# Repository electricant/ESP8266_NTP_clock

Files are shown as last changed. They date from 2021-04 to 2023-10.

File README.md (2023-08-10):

# ESP8266_NTP_clock
Very basic bedside digital clock using the NTP8266 to sync the time using NTP.

## Features

This started as a whish list and expanded during development. Since this is an
open-ended project this list may grow. Never settle!

 * Synchronize time using my local network NTP server
 * Receive and display temperature and humidity readings from my external
   weather station. This way I know at a glance how to get dressed in the
   morning.
 * Backlight support either triggered by a button or automating using a
   photoresistor
 * DST support without requiring an external library

## Firmware

Required libraries:
 * PubSubClient
 * TimeLib
 * ArduinoJson
 * [qd_sched](https://github.com/electricant/qd_sched) - simple scheduler for repetitive tasks

The code uses a local, improved version of the EasyNTPClient library. It is
available as a git submodule.

## PCB/Mechanical assembly

There's not much to it actually. Just a PCB the same size of the display.
The display board and the control PCB are sandwiched together using M2.5 hex
standoffs. The display conencts to the mainboard using 2.54mm headers.

## Pictures

3D rendering of the PCB:
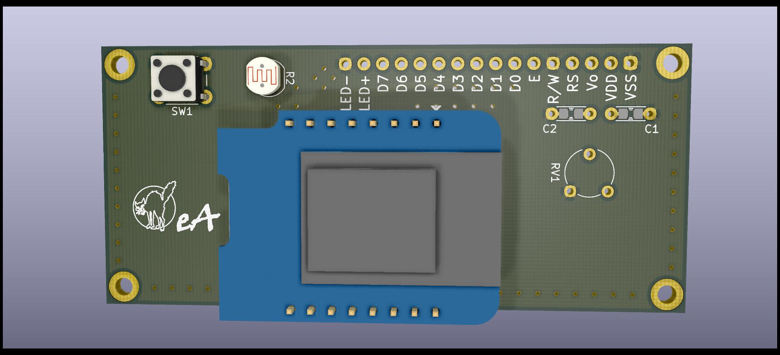
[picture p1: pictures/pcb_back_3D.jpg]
PCB 3D rendering


Prototype (I swear it is not a bomb officer):
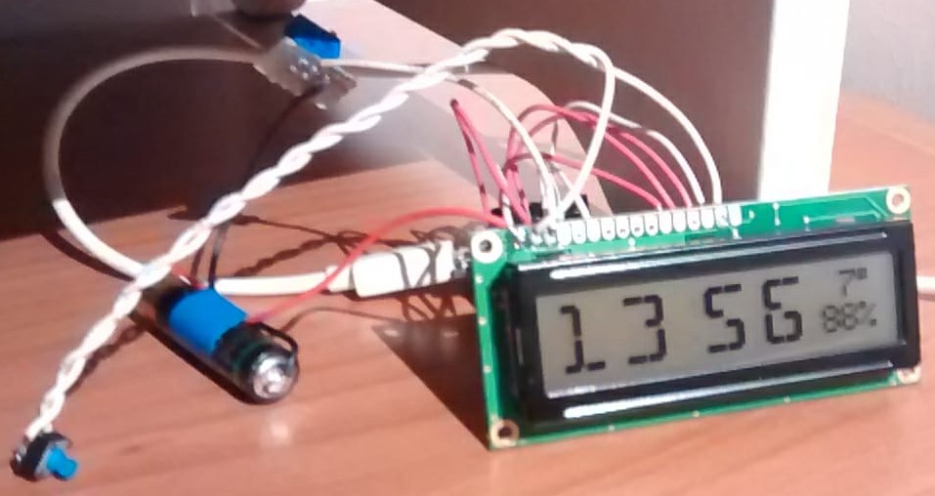
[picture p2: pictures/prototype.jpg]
prototype


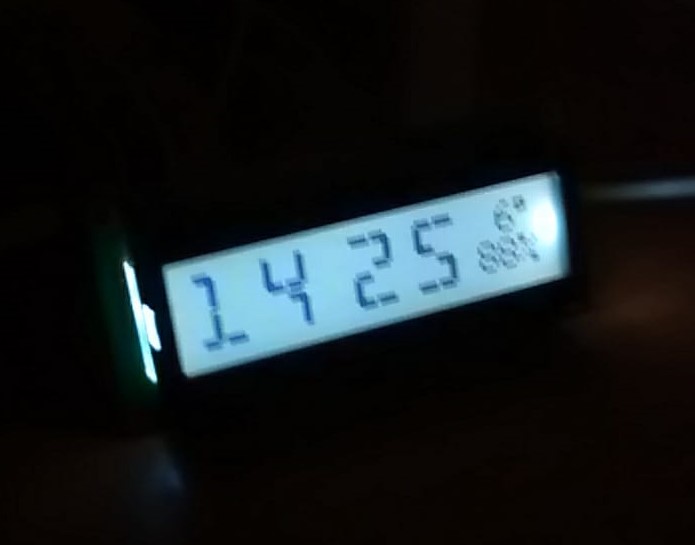
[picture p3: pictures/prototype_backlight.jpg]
prototype backlight


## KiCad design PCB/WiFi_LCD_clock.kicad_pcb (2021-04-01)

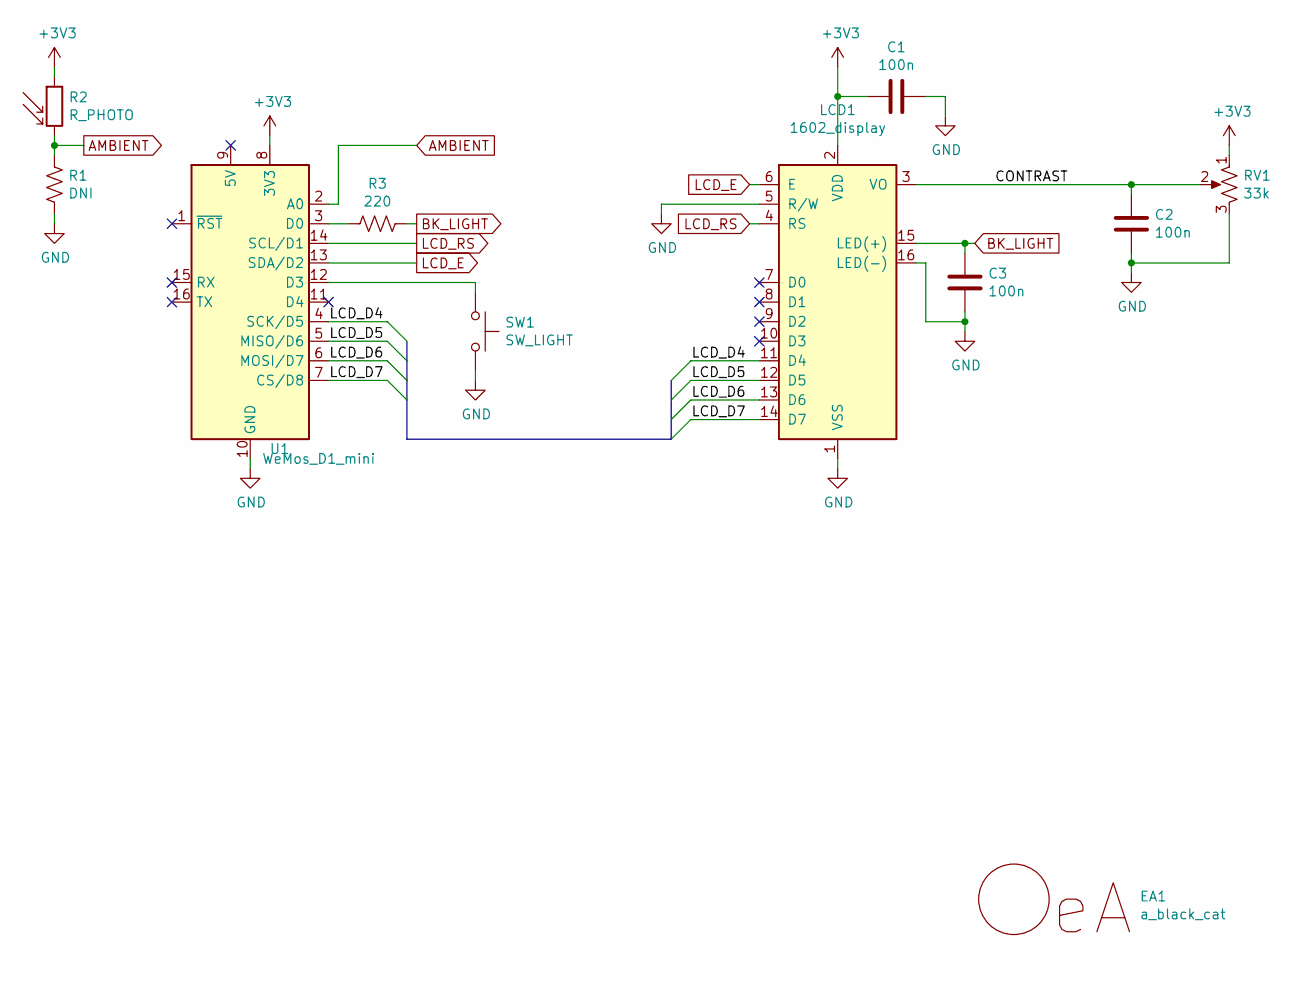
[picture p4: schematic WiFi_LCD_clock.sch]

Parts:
C1, C2, C3: 100n; universal_cap
EA1: a_black_cat
LCD1: 1602_display; 1602_lcd
R1: DNI; universal_res
R2: R_PHOTO; R_LDR_4.9x4.2mm_P2.54mm_Vertical
R3: 220; universal_res
RV1: 33k; Potentiometer_Piher_PT-6-V_Vertical
SW1: SW_LIGHT; SW_PUSH_6mm
U1: WeMos_D1_mini; WEMOS_D1_mini_light

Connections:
+3V3: C1.2, LCD1.2 (VDD), R2.1, RV1.1, U1.8 (3V3)
/CONTRAST: C2.1, LCD1.3 (VO), RV1.2
/LCD_D4: LCD1.11 (D4), U1.4 (SCK/D5)
/LCD_D5: LCD1.12 (D5), U1.5 (MISO/D6)
/LCD_D6: LCD1.13 (D6), U1.6 (MOSI/D7)
/LCD_D7: LCD1.14 (D7), U1.7 (CS/D8)
AMBIENT: R1.1, R2.2, U1.2 (A0)
BK_LIGHT: C3.1, LCD1.15 (LED(+)), R3.1
GND: C1.1, C2.2, C3.2, LCD1.1 (VSS), LCD1.5 (R/W), LCD1.16 (LED(-)), R1.2, RV1.3, SW1.2, U1.10 (GND)
LCD_E: LCD1.6 (E), U1.13 (SDA/D2)
LCD_RS: LCD1.4 (RS), U1.14 (SCL/D1)
unnamed: R3.2, U1.3 (D0)
unnamed: SW1.1, U1.12 (D3)

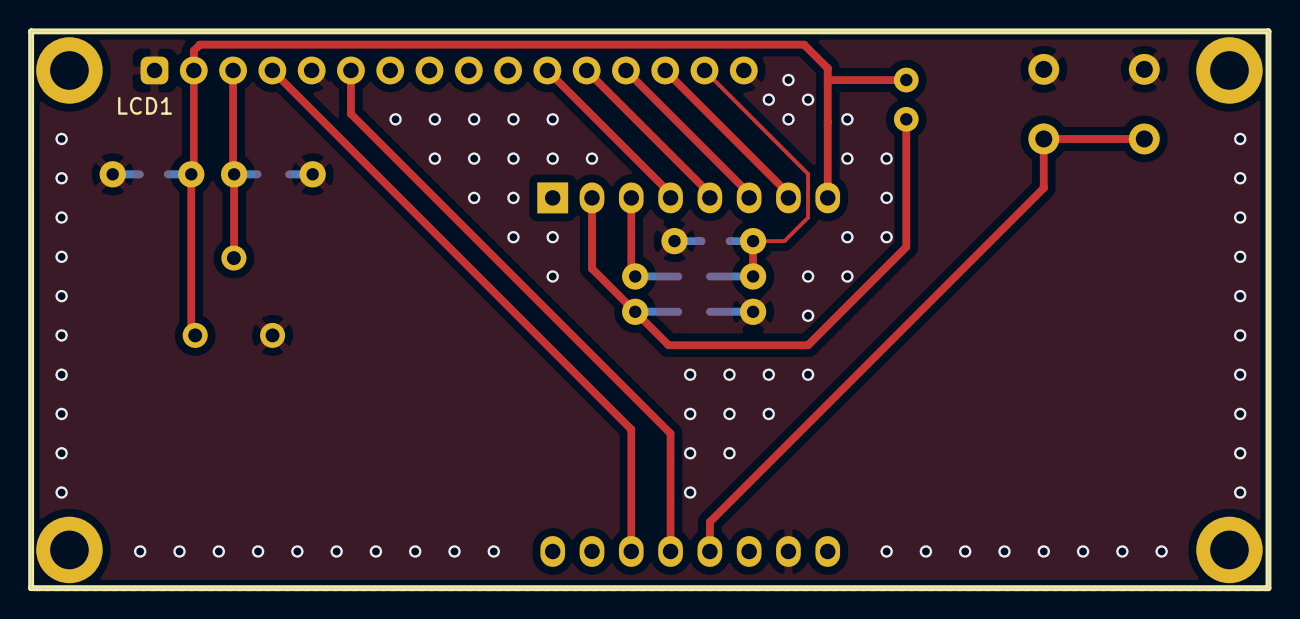
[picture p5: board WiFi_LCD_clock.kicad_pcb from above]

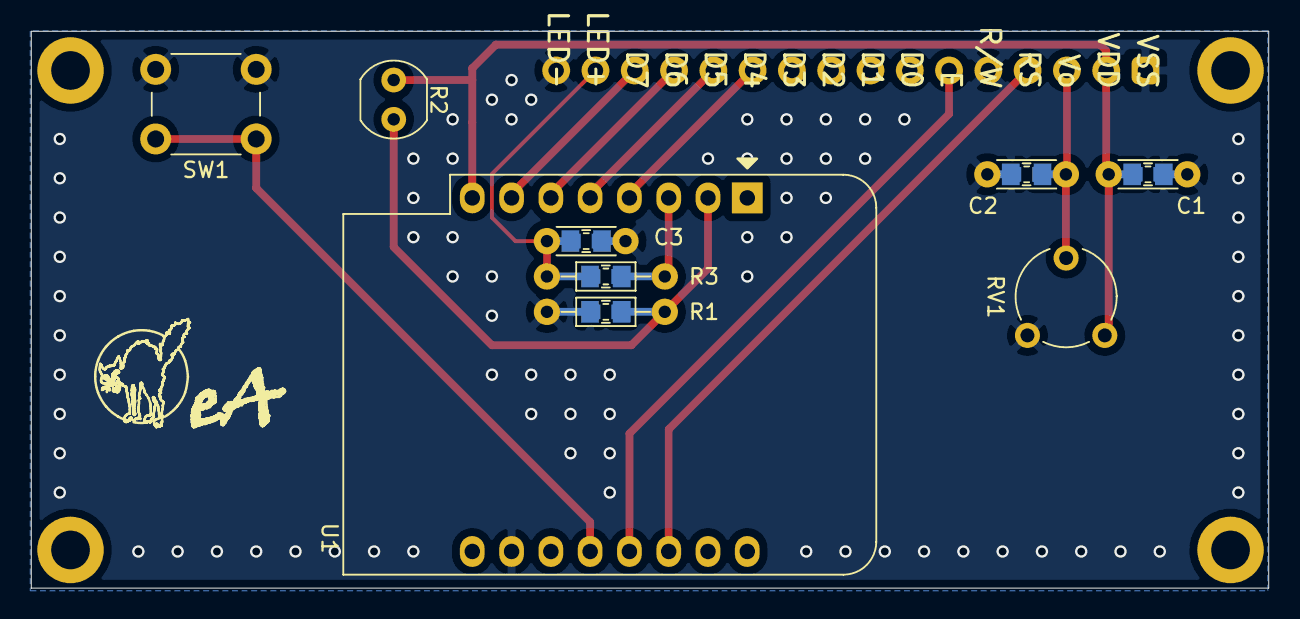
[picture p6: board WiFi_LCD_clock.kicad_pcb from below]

Board: 2 copper layers, 80.0 x 36.0 mm, 11 parts (10 on the bottom side), 13 nets.

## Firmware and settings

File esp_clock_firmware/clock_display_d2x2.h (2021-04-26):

/*
 * Header file for the functions controlling the LCD display of the clock.
 *
 * It uses a 2x2 font for displaying the digits.
 *
 * The fonts are defined by a set of 8 custom chars which, combined, look like
 * digits. The custom chars are loaded when the display is initialized and are
 * defined by the chrN (0<= N < 8) arrays.
 * The way in which the custom chars are combined to form digits is defined in
 * the 'number_chars' array. This array has an entry for each digit. Within this
 * entry the index of the custom chars from left to right, top to bottom is present.	
 */
#ifndef CLOCK_DISPLAY_D2X2_H
#define CLOCK_DISPLAY_D2X2_H

#include <LiquidCrystal.h>
#include <pins_arduino.h>

/*
 * LCD pins definition. As seen in the schematic!
 */
#define LCD_RS D1
#define LCD_E  D2
#define LCD_D4 D5
#define LCD_D5 D6
#define LCD_D6 D7
#define LCD_D7 D8

// Global LCD instance
LiquidCrystal lcd = LiquidCrystal(LCD_RS, LCD_E, LCD_D4, LCD_D5, LCD_D6, LCD_D7);

/*
 * Custom chars
 */
byte chr0[] = {
  B01111,
  B11111,
  B11000,
  B11000,
  B11000,
  B11000,
  B11000,
  B11000
};
byte chr1[] = {
  B11110,
  B11111,
  B00011,
  B00011,
  B00011,
  B00011,
  B00011,
  B00011
};
byte chr2[] = {
  B11000,
  B11000,
  B11000,
  B11000,
  B11000,
  B11000,
  B11111,
  B01111
};
byte chr3[] = {
  B00011,
  B00011,
  B00011,
  B00011,
  B00011,
  B00011,
  B11111,
  B11110
};
byte chr4[] = {
  B11111,
  B11111,
  B00000,
  B00000,
  B00000,
  B00000,
  B00000,
  B00000
};
byte chr5[] = {
  B01111,
  B11111,
  B11000,
  B11000,
  B11000,
  B11000,
  B11111,
  B01111
};
byte chr6[] = {
  B11110,
  B11111,
  B00011,
  B00011,
  B00011,
  B00011,
  B11111,
  B11110
};
byte chr7[] = {
  B00000,
  B00000,
  B00000,
  B00000,
  B00000,
  B00000,
  B11111,
  B11111
};

byte number_chars[10][4] = {
  {0,  1,  2, 3}, // 0
  {1, 32,  3, 7}, // 1
  {4,  6,  5, 7}, // 2
  {4,  6,  7, 3}, // 3
  {2,  3, 32, 1}, // 4
  {5,  4,  7, 6}, // 5
  {5,  4,  2, 6}, // 6
  {4,  1, 32, 0}, // 7
  {5,  6,  2, 3}, // 8
  {5,  6,  7, 3}  // 9 
};

/*
 * Initialize the LCD display
 */
void lcd_init();

/*
 * Prints the given time on the LCD
 */
void lcd_print_time(uint8_t hrs, uint8_t mins);
void lcd_print_time(uint8_t hrs, uint8_t mins, uint8_t sec);

/*
 * Prints temperature and humidity
 */
void lcd_print_temp_humidity(float temp, float hum);

#endif

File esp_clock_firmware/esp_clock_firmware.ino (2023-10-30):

/*
    Digital clock with LCD display using a Wemos D1 / ESP8266

    Features:
     - Time is fetched using NTP
     - Also the weather is fetched from the network
*/
#include <ESP8266WiFi.h>
#include <PubSubClient.h>
#include <WiFiUdp.h>
#include "EasyNTPClient/src/EasyNTPClient.h"
#include "EasyNTPClient/src/EasyNTPClient.cpp"
#include <TimeLib.h>
#include <qd_sched.h>
#include <ArduinoJson.h>

#include "clock_display_d2x2.h"
#include "ash.h"
#include "alogger.h"
#include "config/config.h"

/*
 * Macros for hardware configuration.
 * 
 * See 'clock_display_d2x2.h' for macros defining where the display is connected
 */
// Input pin to enable backlight when pressed
#define BACKLIGHT_BUTTON D3
// Output pin to be used as LCD backlight control
#define BACKLIGHT_PIN D0

/* 
 * The controls for the builtin LED are reversed.
 * When the pin is set to HIGH the LED is off and vice-versa.
 * Those two macors make it easy to set the LED state appropriately.
 */
#define LED_BUILTIN_ON  0
#define LED_BUILTIN_OFF 1

// A UDP instance to let us send and receive packets over UDP
WiFiUDP udp;

// EasyNTPClient instance to fetch the current NTP time
#define OFFSET_FROM_UTC_S ((OFFSET_FROM_UTC_H*60*60)+(OFFSET_FROM_UTC_M*60))
EasyNTPClient ntpClient(udp, NTP_SERVER, OFFSET_FROM_UTC_S);

// MQTT client to receive temperature updates
WiFiClient wifiClient;
PubSubClient mqttClient(wifiClient);

// last temperature and humidity readings
float temperature, humidity;

/**
 * Initialize the various GPIOs
 */ 
void gpios_init()
{
  // initialize onboard LED as output
  pinMode(LED_BUILTIN, OUTPUT);
  // set BACKLIGHT_BUTTON pin as input pullup to detect button press
  pinMode(BACKLIGHT_BUTTON, INPUT_PULLUP);
  // also set the backlight pin as output
  pinMode(BACKLIGHT_PIN, OUTPUT);
  // set PWM frequency to minimum to lower CPU load
  analogWriteFreq(100);
}

void setup() {
  // Light sleep can be used only if the WiFi is in STA mode
  WiFi.mode(WIFI_STA);
  WiFi.setSleepMode(WIFI_LIGHT_SLEEP);
  
  // initialize serial port
  Serial.begin(115200);
  while(!Serial) { }
  Serial.println();

  lcd_init();
  // Inform the user that we are loading
  lcd.blink();

  gpios_init();

  // connect to the wifi network
  digitalWrite(LED_BUILTIN, LED_BUILTIN_ON);
  Serial.print("[WiFi] Connecting to ");
  Serial.print(WIFI_SSID);

  WiFi.hostname(WIFI_HOSTNAME);
  WiFi.begin(WIFI_SSID, WIFI_PASS);

  while (WiFi.status() != WL_CONNECTED)
  {
    delay(250);
    Serial.print(".");
  }

  Serial.print("\n[Wifi] Connected. RSSI = ");
  Serial.print(WiFi.RSSI());
  Serial.println(" dBm");
  digitalWrite(LED_BUILTIN, LED_BUILTIN_ON);

  // setup timeLib to use NTP
  setSyncInterval(NTP_SYNC_INTERVAL_M * 60); // seconds see: https://github.com/PaulStoffregen/Time
  setSyncProvider(getNTPtime);
  
  // Initialize MQTT
  mqttClient.setServer(MQTT_BROKER, MQTT_PORT);
  mqttClient.setCallback(mqttSubCallback);
  // set MQTT keepalive value to allow for a safety margin
  mqttClient.setKeepAlive(2*MQTT_UPDATE_MS/1000);

  // setup tasks
  sched_put_task(&backlightTask, BACKLIGHT_UPDATE_MS, true);
  sched_put_task(&screenUpdateTask, SCREEN_UPDATE_MS, true);
  sched_put_task(&mqttLoopTask, MQTT_UPDATE_MS, true);
  sched_put_task(&ashTask, 1000, false);
  
  // done loading
  lcd.noBlink();
  digitalWrite(LED_BUILTIN, LED_BUILTIN_OFF);
}

/**
 * Function to control the backlight.
 * 
 * It uses a state machine that reads two inputs: the backlight buttona and the ambient light.
 * backlight_state_t describes the state the machine is.
 * Depending on the state the backlight can be either on or off.
 */
enum backlight_state_t {
  BKL_IDLE,   // backlight idle (off)
  BKL_MANUAL, // backlight turned on manually (button pressed)
  BKL_AUTO    // backlight turned on automatically (tiriggered by the ambient light sensor)
};
typedef enum backlight_state_t backlight_state_t;

void backlightTask() {
  // keep track of the current state (start in idle mode)
  static backlight_state_t state = BKL_IDLE;
  // used to keep the backlight on for some time after the button has been pressed
  static byte backlightTimer = 0;
  // current ambient light reading
  uint16_t ambientLight = analogRead(A0);

  switch (state) {
    case BKL_IDLE:
      digitalWrite(BACKLIGHT_PIN, 0);
      
      if (digitalRead(BACKLIGHT_BUTTON) == 0) {
        state = BKL_MANUAL;
        backlightTimer = BACKLIGHT_DURATION_TICKS;
        LOG_INFO("Moving to state %i. Reason: backlight button press.", state);
      } else if (ambientLight > BACKLIGHT_ON_THRESHOLD) {
        state = BKL_AUTO;
        LOG_INFO("Moving to state %i. Reason: ambient light.", state);
      }
      break;
    
    case BKL_MANUAL:
      analogWrite(BACKLIGHT_PIN, BACKLIGHT_BRIGHTNESS);

      if (backlightTimer == 0) {
        state = BKL_IDLE;
        LOG_INFO("Moving to state %i. Reason: backlight timer expired.", state);
      } else if (digitalRead(BACKLIGHT_BUTTON) == 0)
        backlightTimer = BACKLIGHT_DURATION_TICKS;
      else if (backlightTimer > 0)
        backlightTimer--;
      
      break;
    
    case BKL_AUTO:
      analogWrite(BACKLIGHT_PIN, BACKLIGHT_BRIGHTNESS);

      if (ambientLight < (BACKLIGHT_ON_THRESHOLD - BACKLIGHT_DEADBAND)) {
        state = BKL_IDLE;
        LOG_INFO("Moving to state %i. Reason: ambient light.", state);
      }
      break;
  }
}

/**
 * Function to update the screen contents
 */
void screenUpdateTask() {
  int dst_offset = 0;
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

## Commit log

2021-04-01 Add Kicad PCB desing files.
    [WiFi_LCD_clock-B_Cu.gbr, WiFi_LCD_clock-B_Mask.gbr, WiFi_LCD_clock-B_Paste.gbr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]
2021-04-01 Add pictures of the PCB and the prototype
2021-04-02 Tasks may not be scheduled if millis() overflows. Issue fixed
    [esp_clock_firmware.ino]
2021-04-26 Update code to the new PCB and use the ambient light sensor to control display backlight automatically
2021-05-08 Turn off the builtin LED in case of error in deserializeJson
    [esp_clock_firmware.ino]
2021-12-07 Fix out of memory error when parsing json input string
    [esp_clock_firmware.ino]
2023-10-30 Rework DST logic a bit
    [config-example.h, esp_clock_firmware.ino]
